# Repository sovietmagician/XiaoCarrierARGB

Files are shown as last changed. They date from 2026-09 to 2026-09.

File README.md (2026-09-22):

# XiaoCarrierARGB
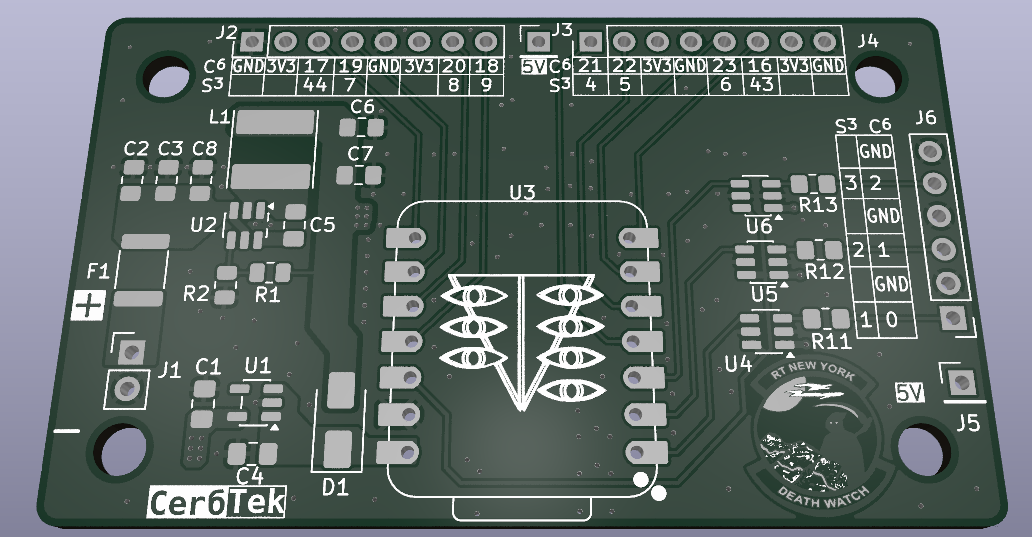
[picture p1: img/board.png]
Board preview

Adressable RGB carrier board for Seeed Xiao Esp32 modules, deisgned for c6 or s3 variants. Input voltage designed to be 12-24V and has an back current protection mechanism to allow the Xiao to be connected to a pc while the board is powered from elsewhere. 
- NOTE the 5v level shifters needed for the RGB data signalling are only powered from the 12-24v input and only connecting the xiao to power will not allow for RGB strip control. 
---
## Features

- 3 Dedicated 5V levelshifted outputs for LED strip data lines
- 8 GPIO breakouts capable of all features the selected Xiao is capable of including
  - SPI
  - I2C
  - Analog inputs
  - UART
- optional pull up/down resistors for GPIO breakouts can be pulled to:
  - 5V
  - 3.3V
  - GND
- 1.5 Amps of 5V output
- 1 Amp of 3.3V output

---

## USER INFO

### BoM
[Interactive Bill of Materials](https://sovietmagician.github.io/XiaoCarrierARGB/bom/ibom.html "IBOM")
Component Manufacturer Part Numbers are included for ICs and certain passives with critical values. In addition Digikey and LCSC(chinese) part distributor numbers are included in the BoM as well. The part numbers for passives have been left blank as an excercise for the reader. Note for C2 C3 C8, __these capacitors must be rated to 30V at a minimum__.
### Notes about componet placement/population
The following components are NOT OPTIONAL
- C2 C3 C5 C6 C7
  - These capacitors are necessary for the operation of the buck converter a provisional value of 22µF was selected but it is possible more may be necessary
- C5
  - Bootstrap capacitor should be 100nF

- L1
  - The main inductor for the buck converter without it it just wont function at all
- D1
  - Needed to allow the Xiao to be both plugged in to a computer and have its primary input voltage connected
- U2
  - The buck converter IC without it it will not accept 12-24V input and the level shifters will not be able to drive the RGB data lines
- R1 R2
  - Feedback resistors to allow the buck to actually regulate to the correct (5) Voltage. These must be populated at the right values in the right spots, R1-110kΩ R2-15kΩ

The following components are highly recommended
- U1 
  - The LDO for the 3.3V pins on the GPIO breakout, while not STRICTLY necessary it is highly recommended 
- C1 C4
  - These 1µF capacitors are necessary for 3.3V LDO functionality to supply power to the power pins accompanying the GPIO breakouts A higher value may be used but the total capacitance on this line MAY NOT exceed 10µF to keep the Xiao's VBUS pin inline with USB spec
- F1
  - Input protection to prevent the board from drawing too much current, should save the board in the event of shorts or overcurrent events
- U4 U5 U6
  - these are the level shifters to drive the LED strips, not all need to be populated but populating none is kind of silly 
- C8
  - A good decoupling cap of 100nF is nice to have and since the previous 100nF cap is necessary theres no real reason not to populate it 
  
The following are strictly optional
- R3-R10
  - these are pull up/down resistors meant to allow for ease of use of the GPIO breakouts some communication busses need pull ups or pull downs and its just usecase dependant
- R11-13
  - these are series resistors meant to minimize reflections in the even of exceptionally long data line runs(ie there is a very long wire between the board and the first IC on the LED strip) can be subbed for 0Ω resistors or pads can be bridged with solder or wire

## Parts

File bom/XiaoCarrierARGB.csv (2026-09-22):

Reference | Qty | Value | DNP | Exclude from BOM | Exclude from Board | Exclude from Simulation | Exclude from Position Files | Footprint | Datasheet | Digikey Part | DigiKey Part
U4,U5,U6 | 3 | 74LVC1T45W6-7 |  |  |  |  | ${EXCLUDE_FROM_POS_FILES} | Package_TO_SOT_SMD:SOT-23-6 | https://www.diodes.com/assets/Datasheets/74LVC1T45.pdf |  | 74LVC1T45W6-7DICT-ND
U3 | 1 | XIAO-ESP32-C6-DIP |  |  |  |  | ${EXCLUDE_FROM_POS_FILES} | Seeed Xiao:XIAO-ESP32-C6-DIP
U2 | 1 | TPP362083-T6TR |  |  |  |  | ${EXCLUDE_FROM_POS_FILES} | Package_TO_SOT_SMD:TSOT-23-6 | https://static.3peak.com/res/doc/ds/Datasheet_TPP36208.pdf |  | 5503-TPP362081-T6TR
U1 | 1 | TLV75733PDBV |  |  |  |  | ${EXCLUDE_FROM_POS_FILES} | Package_TO_SOT_SMD:SOT-23-5 | https://www.ti.com/lit/ds/symlink/tlv757p.pdf |  | 296-50414
R2 | 1 | 15k |  |  |  |  | ${EXCLUDE_FROM_POS_FILES} | Resistor_SMD:R_0805_2012Metric
R1 | 1 | 110k |  |  |  |  | ${EXCLUDE_FROM_POS_FILES} | Resistor_SMD:R_0805_2012Metric
L1 | 1 | 4.7uH |  |  |  |  | ${EXCLUDE_FROM_POS_FILES} | Inductor_SMD:L_Chilisin_BWVS00606045 | https://www.vishay.com/docs/34083/ifsc-2020de-01.pdf |  | 541-IFSC2020DEER4R7M01CT-ND
J6 | 1 | Conn_01x06 |  |  |  |  | ${EXCLUDE_FROM_POS_FILES} | Connector_PinHeader_2.54mm:PinHeader_1x06_P2.54mm_Vertical
J3,J5 | 2 | Conn_01x01 |  |  |  |  | ${EXCLUDE_FROM_POS_FILES} | Connector_PinHeader_2.54mm:PinHeader_1x01_P2.54mm_Vertical
J2,J4 | 2 | Conn_01x08 |  |  |  |  | ${EXCLUDE_FROM_POS_FILES} | Connector_PinHeader_2.54mm:PinHeader_1x08_P2.54mm_Vertical
J1 | 1 | V_{IN}^{10-24V} |  |  |  |  | ${EXCLUDE_FROM_POS_FILES} | Connector_PinHeader_2.54mm:PinHeader_1x02_P2.54mm_Vertical
F1 | 1 | YAGEO SMD1812B110TF/33 |  |  |  |  | ${EXCLUDE_FROM_POS_FILES} | Fuse:Fuse_1812_4532Metric | https://www.mouser.com/datasheet/3/508/1/SMD1812_1.pdf |  | 13-SMD1812B110TF/33
D1 | 1 | D_Schottky |  |  |  |  | ${EXCLUDE_FROM_POS_FILES} | Diode_SMD:D_SMA | https://www.panjit.com.tw/upload/datasheet/SBA520AFC_SERIES.pdf |  | 3757-SBA520AFC_R1_00001
C5,C8 | 2 | 100nF |  |  |  |  | ${EXCLUDE_FROM_POS_FILES} | Capacitor_SMD:C_0805_2012Metric_Pad1.18x1.45mm_HandSolder
C2,C3,C6,C7 | 4 | 22uF |  |  |  |  | ${EXCLUDE_FROM_POS_FILES} | Capacitor_SMD:C_0805_2012Metric_Pad1.18x1.45mm_HandSolder
C1,C4 | 2 | 1uF |  |  |  |  | ${EXCLUDE_FROM_POS_FILES} | Capacitor_SMD:C_0805_2012Metric_Pad1.18x1.45mm_HandSolder

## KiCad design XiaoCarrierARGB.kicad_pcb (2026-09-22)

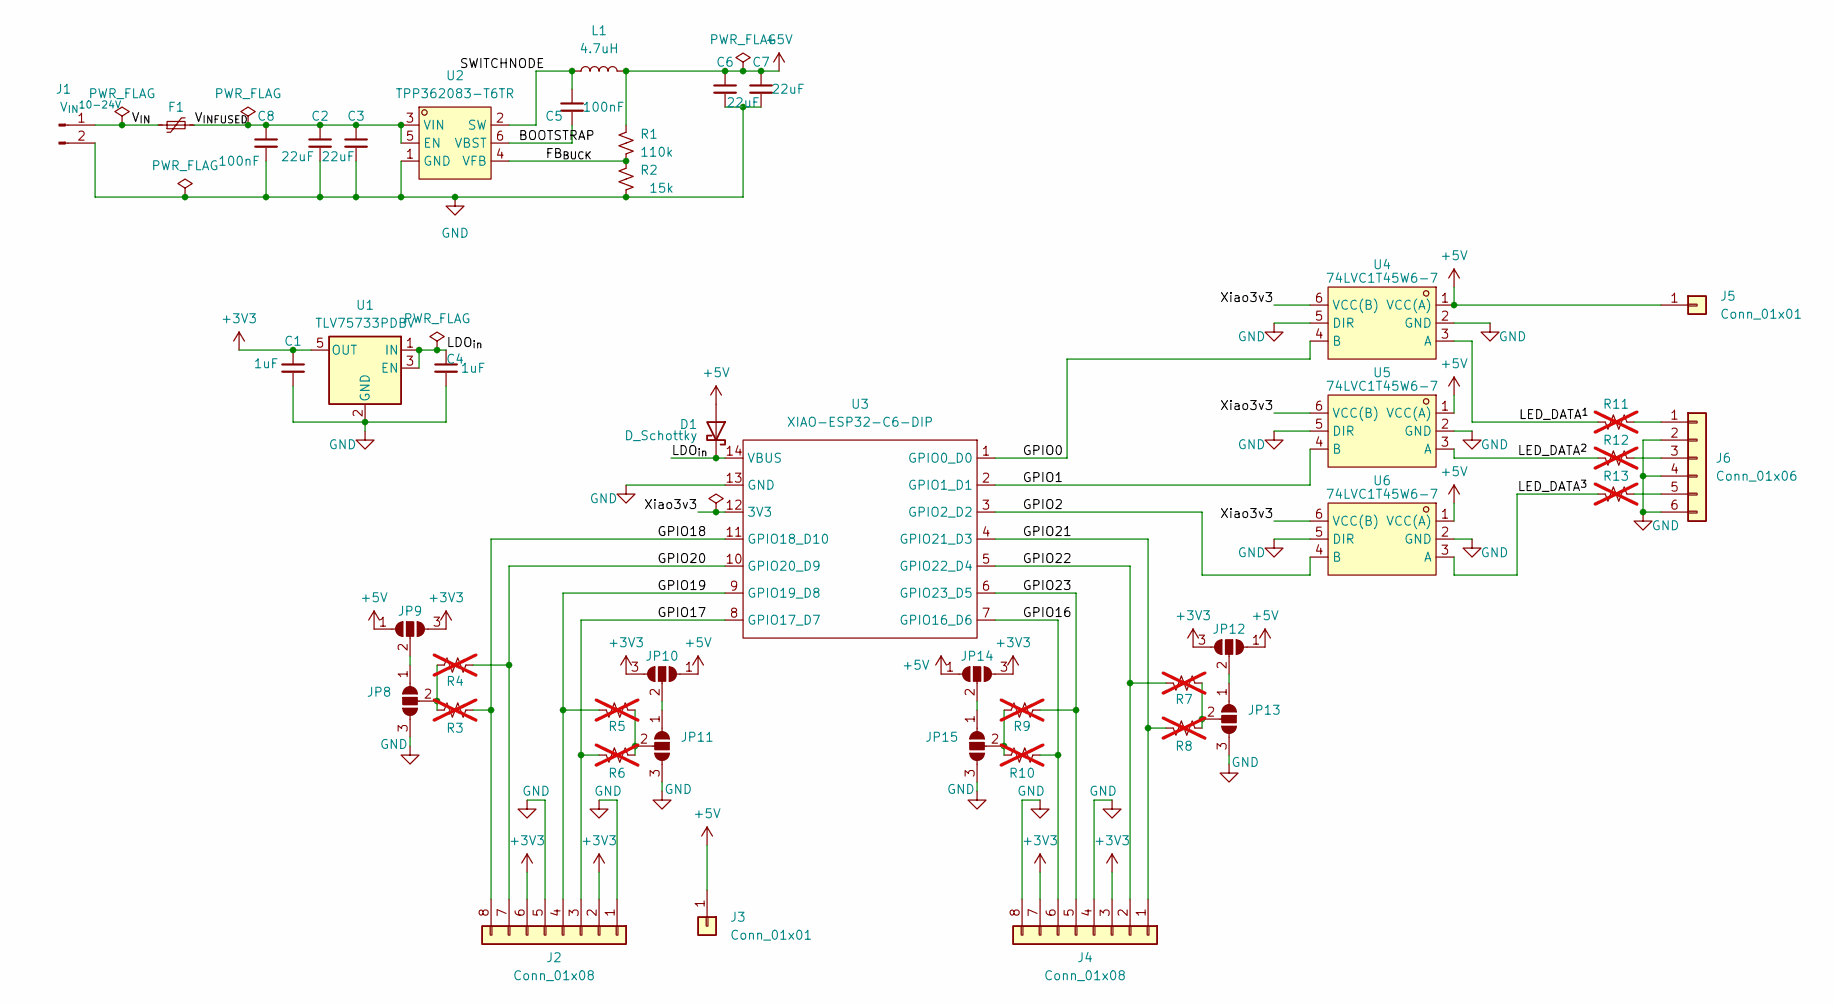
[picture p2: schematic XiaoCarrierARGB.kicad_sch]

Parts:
C1, C4: 1uF; C_0805_2012Metric_Pad1.18x1.45mm_HandSolder
C2, C3, C6, C7: 22uF; C_0805_2012Metric_Pad1.18x1.45mm_HandSolder
C5, C8: 100nF; C_0805_2012Metric_Pad1.18x1.45mm_HandSolder
D1: D_Schottky; D_SMA; MPN SBA520AFC_R1_00001; DigiKey Part 3757-SBA520AFC_R1_00001
F1: YAGEO SMD1812B110TF/33; Fuse_1812_4532Metric; LCSC Part C269134
J1: V_{IN}^{10-24V}; PinHeader_1x02_P2.54mm_Vertical
J2, J4: Conn_01x08; PinHeader_1x08_P2.54mm_Vertical
J3, J5: Conn_01x01; PinHeader_1x01_P2.54mm_Vertical
J6: Conn_01x06; PinHeader_1x06_P2.54mm_Vertical
JP8, JP9, JP10, JP11, JP12, JP13, JP14, JP15: SolderJumper_3_Open; SolderJumper-3_P1.3mm_Open_Pad1.0x1.5mm
L1: 4.7uH; L_Chilisin_BWVS00606045; MPN IFSC2020DEER4R7M01; DigiKey Part 541-IFSC2020DEER4R7M01CT-ND
R1: 110k; R_0805_2012Metric
R2: 15k; R_0805_2012Metric
R3, R4, R5, R6, R7, R8, R9, R10, R11, R12, R13: R_Small_US; R_0805_2012Metric; not fitted
U1: TLV75733PDBV; SOT-23-5; MPN TLV75733PDBVR; DigiKey Part 296-50414
U2: TPP362083-T6TR; TSOT-23-6; MPN TPP362081-T6TR; LCSC Part C29073195
U3: XIAO-ESP32-C6-DIP
U4, U5, U6: 74LVC1T45W6-7; SOT-23-6; MPN 74LVC1T45W6-7; LCSC Part C168856

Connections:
+3V3: C1.1, J2.2, J2.6, J4.3, J4.7, JP9.3 (B), JP10.3 (B), JP12.3 (B), JP14.3 (B), U1.5 (OUT)
+5V: C6.1, C7.1, D1.2 (A), J3.1 (Pin_1_1), J5.1 (Pin_1_1), JP9.1 (A), JP10.1 (A), JP12.1 (A), JP14.1 (A), L1.2, R1.1, U4.1 (VCC(A)), U5.1 (VCC(A)), U6.1 (VCC(A))
/BOOTSTRAP: C5.1, U2.6 (VBST)
/FB_{BUCK}: R1.2, R2.1, U2.4 (VFB)
/GPIO0: U3.1 (GPIO0_D0), U4.4 (B)
/GPIO1: U3.2 (GPIO1_D1), U5.4 (B)
/GPIO2: U3.3 (GPIO2_D2), U6.4 (B)
/GPIO16: J4.6, R10.2, U3.7 (GPIO16_D6)
/GPIO17: J2.3, R6.2, U3.8 (GPIO17_D7)
/GPIO18: J2.8, R3.2, U3.11 (GPIO18_D10)
/GPIO19: J2.4, R5.2, U3.9 (GPIO19_D8)
/GPIO20: J2.7, R4.2, U3.10 (GPIO20_D9)
/GPIO21: J4.1, R8.2, U3.4 (GPIO21_D3)
/GPIO22: J4.2, R7.2, U3.5 (GPIO22_D4)
/GPIO23: J4.5, R9.2, U3.6 (GPIO23_D5)
/LDO_{in}: C4.1, D1.1 (K), U1.1 (IN), U1.3 (EN), U3.14 (VBUS)
/LED_DATA^{1}: R11.2, U4.3 (A)
/LED_DATA^{2}: R12.2, U5.3 (A)
/LED_DATA^{3}: R13.2, U6.3 (A)
/SWITCHNODE: C5.2, L1.1, U2.2 (SW)
/V_{IN}: F1.1, J1.1
/V_{IN}_{FUSED}: C2.1, C3.1, C8.2, F1.2, U2.3 (VIN), U2.5 (EN)
/Xiao3v3: U3.12 (3V3), U4.6 (VCC(B)), U5.6 (VCC(B)), U6.6 (VCC(B))
GND: C1.2, C2.2, C3.2, C4.2, C6.2, C7.2, C8.1, J1.2, J2.1, J2.5, J4.4, J4.8, J6.2, J6.4, J6.6, JP8.3 (B), JP11.3 (B), JP13.3 (B), JP15.3 (B), R2.2, U1.2 (GND), U2.1 (GND), U3.13 (GND), U4.2 (GND), U4.5 (DIR), U5.2 (GND), U5.5 (DIR), U6.2 (GND), U6.5 (DIR)
unnamed: J6.1, R11.1
unnamed: J6.3, R12.1
unnamed: J6.5, R13.1
unnamed: JP8.1 (A), JP9.2 (C)
unnamed: JP8.2 (C), R3.1, R4.1
unnamed: JP10.2 (C), JP11.1 (A)
unnamed: JP11.2 (C), R5.1, R6.1
unnamed: JP12.2 (C), JP13.1 (A)
unnamed: JP13.2 (C), R7.1, R8.1
unnamed: JP14.2 (C), JP15.1 (A)
unnamed: JP15.2 (C), R9.1, R10.1

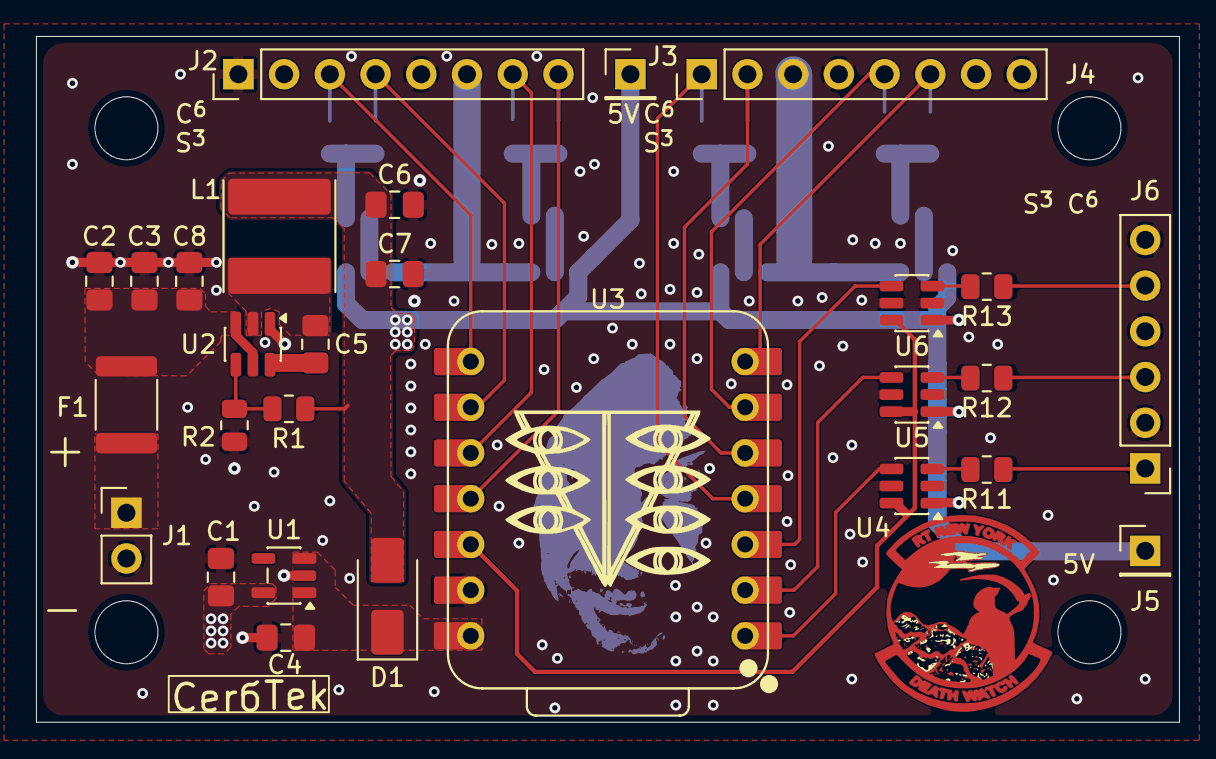
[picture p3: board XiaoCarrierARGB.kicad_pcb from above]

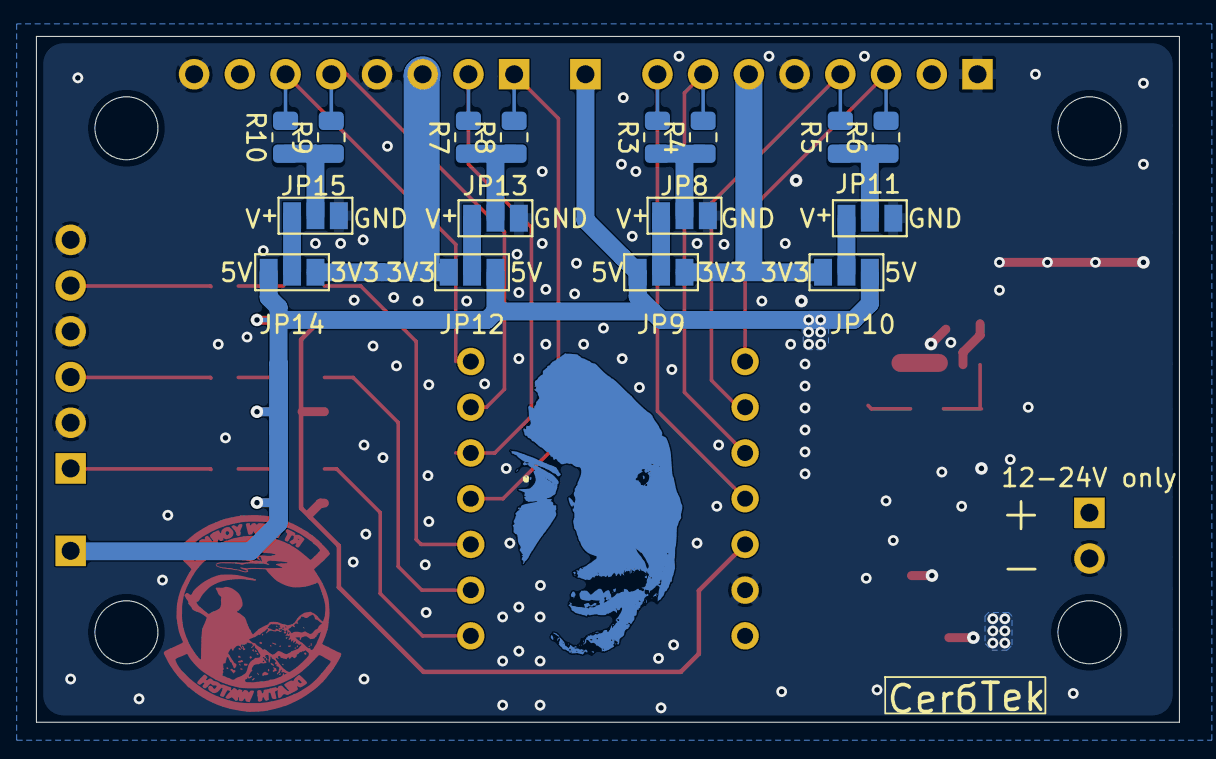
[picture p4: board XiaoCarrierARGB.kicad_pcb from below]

Board: 4 copper layers, 63.5 x 38.1 mm, 45 parts (16 on the bottom side), 35 nets.

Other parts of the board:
RT**: RT-NY; RT-NY-Patch

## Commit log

2026-09-12 Added Buck
    TPP362081 added to library and schematic, might switch exact model from TPP362081 to TPP362083
    [XiaoCarrierARGB.kicad_sch]
2026-09-13 added LDO and level shifters.
    most footprint assingments done, need to source ptc fuse and decide on if pullups or pulldowns should be placed but not populated for versatility
    [XiaoCarrierARGB.kicad_sch]
2026-09-13 Sourced PTC fuse
    [XiaoCarrierARGB.kicad_sch]
2026-09-14 Switched Buck
    switched to TPP362083-T6TR to use forced PWM and avoid skip pulse noise
    [XiaoCarrierARGB.kicad_sch]
2026-09-14 Mostly Finalized Schematic added footprint assignments and most BOM entries
    [XiaoCarrierARGB.kicad_sch]
2026-09-14 Started rough Layout considering dropping board size to 1.5in x2.5in 4 layers might be excessive
    [XiaoCarrierARGB.kicad_pcb, XiaoCarrierARGB.kicad_sch]
2026-09-14 adjusted prelim layout
    [XiaoCarrierARGB.kicad_pcb]
2026-09-14 moved to 4 layers
    [XiaoCarrierARGB.kicad_pcb]
2026-09-14 realigned schem grid added netclass assignment and net names
    [XiaoCarrierARGB.kicad_pcb, XiaoCarrierARGB.kicad_sch]
2026-09-14 started prettying it up a bit
    [XiaoCarrierARGB.kicad_pcb]
2026-09-15 Did mostly all layout need to sanity check and review
    [XiaoCarrierARGB.kicad_pcb, XiaoCarrierARGB.kicad_sch]
2026-09-15 added jumpers and Rs for possible pullup pulldown on gpio also added r to data out lines to allow for compensation in long data lines
    [XiaoCarrierARGB.kicad_sch]
2026-09-15 Refactored layout, added jumpers and unpopulated pull up/down Rs to backside of board
    [XiaoCarrierARGB.kicad_pcb, XiaoCarrierARGB.kicad_sch]
2026-09-16 Finished up layout
    Need to do final sanity checks BUCK and such
    [XiaoCarrierARGB.kicad_pcb, XiaoCarrierARGB.kicad_sch]
2026-09-16 Added ground fills to top and bottom layers Silkscreen layout needs to be done for easy pin ID
    [XiaoCarrierARGB.kicad_pcb]
2026-09-16 changed net colors
    [XiaoCarrierARGB.kicad_pcb]
2026-09-16 Set PWR rail net colors individually
2026-09-16 started GPIO silk marking table
    [XiaoCarrierARGB.kicad_pcb]
2026-09-16 Did GPIO numbering Table on Fsilk
    [XiaoCarrierARGB.kicad_pcb]
2026-09-16 Rework on 3v3 gpio breakout traces maybe switch thick trace to pour on inner layer
    [XiaoCarrierARGB.kicad_pcb]
2026-09-17 finalized design
    [XiaoCarrierARGB.kicad_pcb]
2026-09-17 moved via
    [XiaoCarrierARGB.kicad_pcb]
2026-09-17 moved refdes for u4
    [XiaoCarrierARGB.kicad_pcb]
2026-09-17 more cleaning up etc
    [XiaoCarrierARGB.kicad_pcb]
2026-09-17 generated gerbers and ibom
    [XiaoCarrierARGB.GBL, XiaoCarrierARGB.GBO, XiaoCarrierARGB.GBP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]
2026-09-17 added board preview img to README
2026-09-17 Added board color and finish to PCB stackup
    [XiaoCarrierARGB.kicad_pcb]
2026-09-17 added +- inidcators to Vin changed optional passives footprints to more hand solder friendly footprints
    [XiaoCarrierARGB.kicad_pcb]
2026-09-17 moved some stuff ensure screw terminal compatibility w at least VIN and Data line connections
    [XiaoCarrierARGB.kicad_pcb]
2026-09-17 added some silk screen
    [XiaoCarrierARGB.kicad_pcb]
2026-09-17 regen gerbs
    [XiaoCarrierARGB.GBL, XiaoCarrierARGB.GBO, XiaoCarrierARGB.GBP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]
2026-09-18 Finalized Design export gerbers for manufacturing
    [XiaoCarrierARGB.GBL, XiaoCarrierARGB.GBO, XiaoCarrierARGB.GBP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]
2026-09-18 Redid board 3d render to use green mask
    [XiaoCarrierARGB.kicad_pcb]
2026-09-18 negligible change
    [XiaoCarrierARGB.kicad_pcb]
2026-09-22 ReExport BOM
    [XiaoCarrierARGB.csv, XiaoCarrierARGB.kicad_sch]
2026-09-22 BOM exported again
    [XiaoCarrierARGB.kicad_pcb]
